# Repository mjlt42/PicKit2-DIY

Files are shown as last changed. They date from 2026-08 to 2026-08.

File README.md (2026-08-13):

PicKit 2 Bootloader Clone

# Description
This is clone of a PicKit 2, which is a bootloader for PIC MCU chips; requires a pre programmed chip to opperate. 

## Schematic:


## Bill Of Materials
| Reference | Qty | Value | Footprint | Datasheet |
| :--- | :---: | :--- | :--- | :--- |
| C1 | 1 | 47uF | JLCImport:ERS1KM470F12OT | — |
| C2, C3 | 2 | 22pF | JLCImport:CC1H220KA1EDCH4B1100 | — |
| C4 | 1 | 0.47uF | JLCImport:178MU0009 | — |
| C5 | 1 | 0.1uF | JLCImport:178MU0006 | — |
| D1 | 1 | BAT41 | JLCImport:BAT41 | [Datasheet](http://www.vishay.com/docs/85659/bat41.pdf) |
| D2 | 1 | 1N5817 | JLCImport:1N5817_C7544876 | [Datasheet](http://www.vishay.com/docs/88525/1n5817.pdf) |
| D3, D4 | 2 | LED | LED_THT:LED_D5.0mm | — |
| J1 | 1 | Conn_01x06_Socket | JLCImport:2_54-1_6PHeader-RA | — |
| J4 | 1 | USB_C_Receptacle_USB2.0_16P | JLCImport:KH-TYPE-C-16P | [Link](https://www.usb.org/sites/default/files/documents/usb_type-c.zip) |
| L1 | 1 | 680uH | JLCImport:YAL0410-681K | — |
| Q1, Q2, Q4 | 3 | 2N3904 | JLCImport:2N3904_C2874602 | [Datasheet](https://www.onsemi.com/pub/Collateral/2N3903-D.PDF) |
| Q3 | 1 | 2N3906 | JLCImport:2N3906_C2874603 | [Datasheet](https://www.onsemi.com/pub/Collateral/2N3906-D.PDF) |
| R1 | 1 | 1K | JLCImport:MF1_4W-1K_1_T52 | — |
| R2, R10, R15, R16 | 4 | 4.7K | JLCImport:MF1_4W-4_7K_1_T52 | — |
| R3 | 1 | 2.7K | JLCImport:MF1_4W-2_7K_1_T52 | — |
| R4 | 1 | 100K | JLCImport:MF1_4W-100K_1_T52 | — |
| R5, R6, R9 | 3 | 10K | JLCImport:MFR0W4F1002A50 | — |
| R7, R11 | 2 | 330 | JLCImport:MFR0W4F3300A50 | — |
| R8, R12, R13, R17 | 4 | 100 | JLCImport:MFR0W4F1000A50 | — |
| R14 | 1 | 22K | JLCImport:MF1_4W-22K_1_T52 | — |
| R18, R19 | 2 | 5.1K | JLCImport:MF1_4W-5_1K_1_T52 | — |
| SW1 | 1 | SW_Push | Button_Switch_THT:SW_PUSH_6mm | — |
| U1 | 1 | PIC18F2550-ISP | Package_DIP:DIP-28_W7.62mm | [Datasheet](http://ww1.microchip.com/downloads/en/devicedoc/39632c.pdf) |
| X1 | 1 | 20Mhz | JLCImport:X49ST2-20_000-F20JGDT | — |

## PCB Layout:
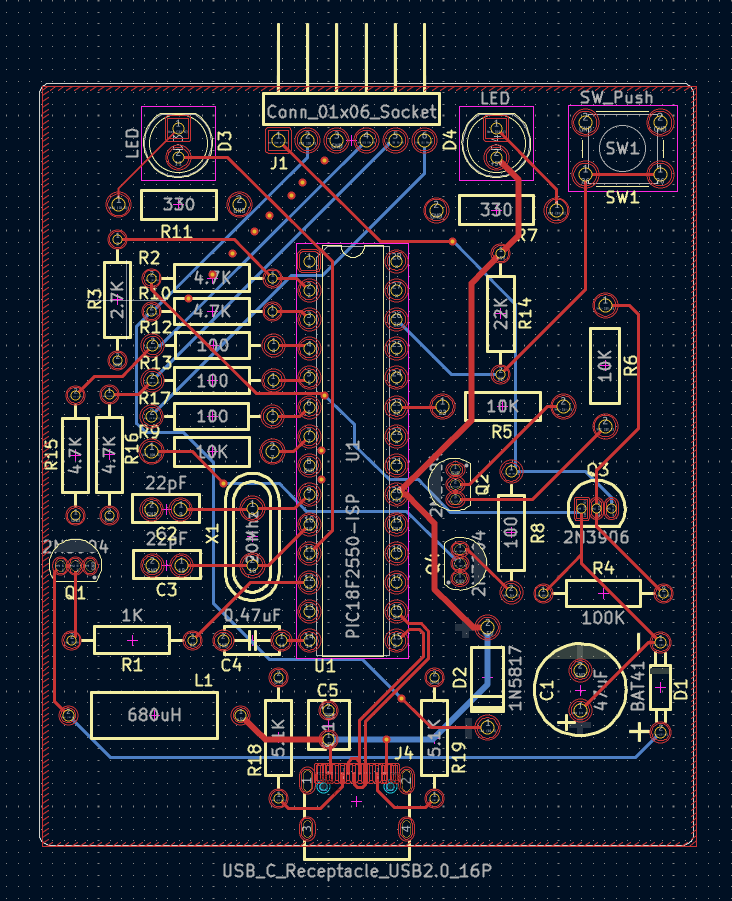
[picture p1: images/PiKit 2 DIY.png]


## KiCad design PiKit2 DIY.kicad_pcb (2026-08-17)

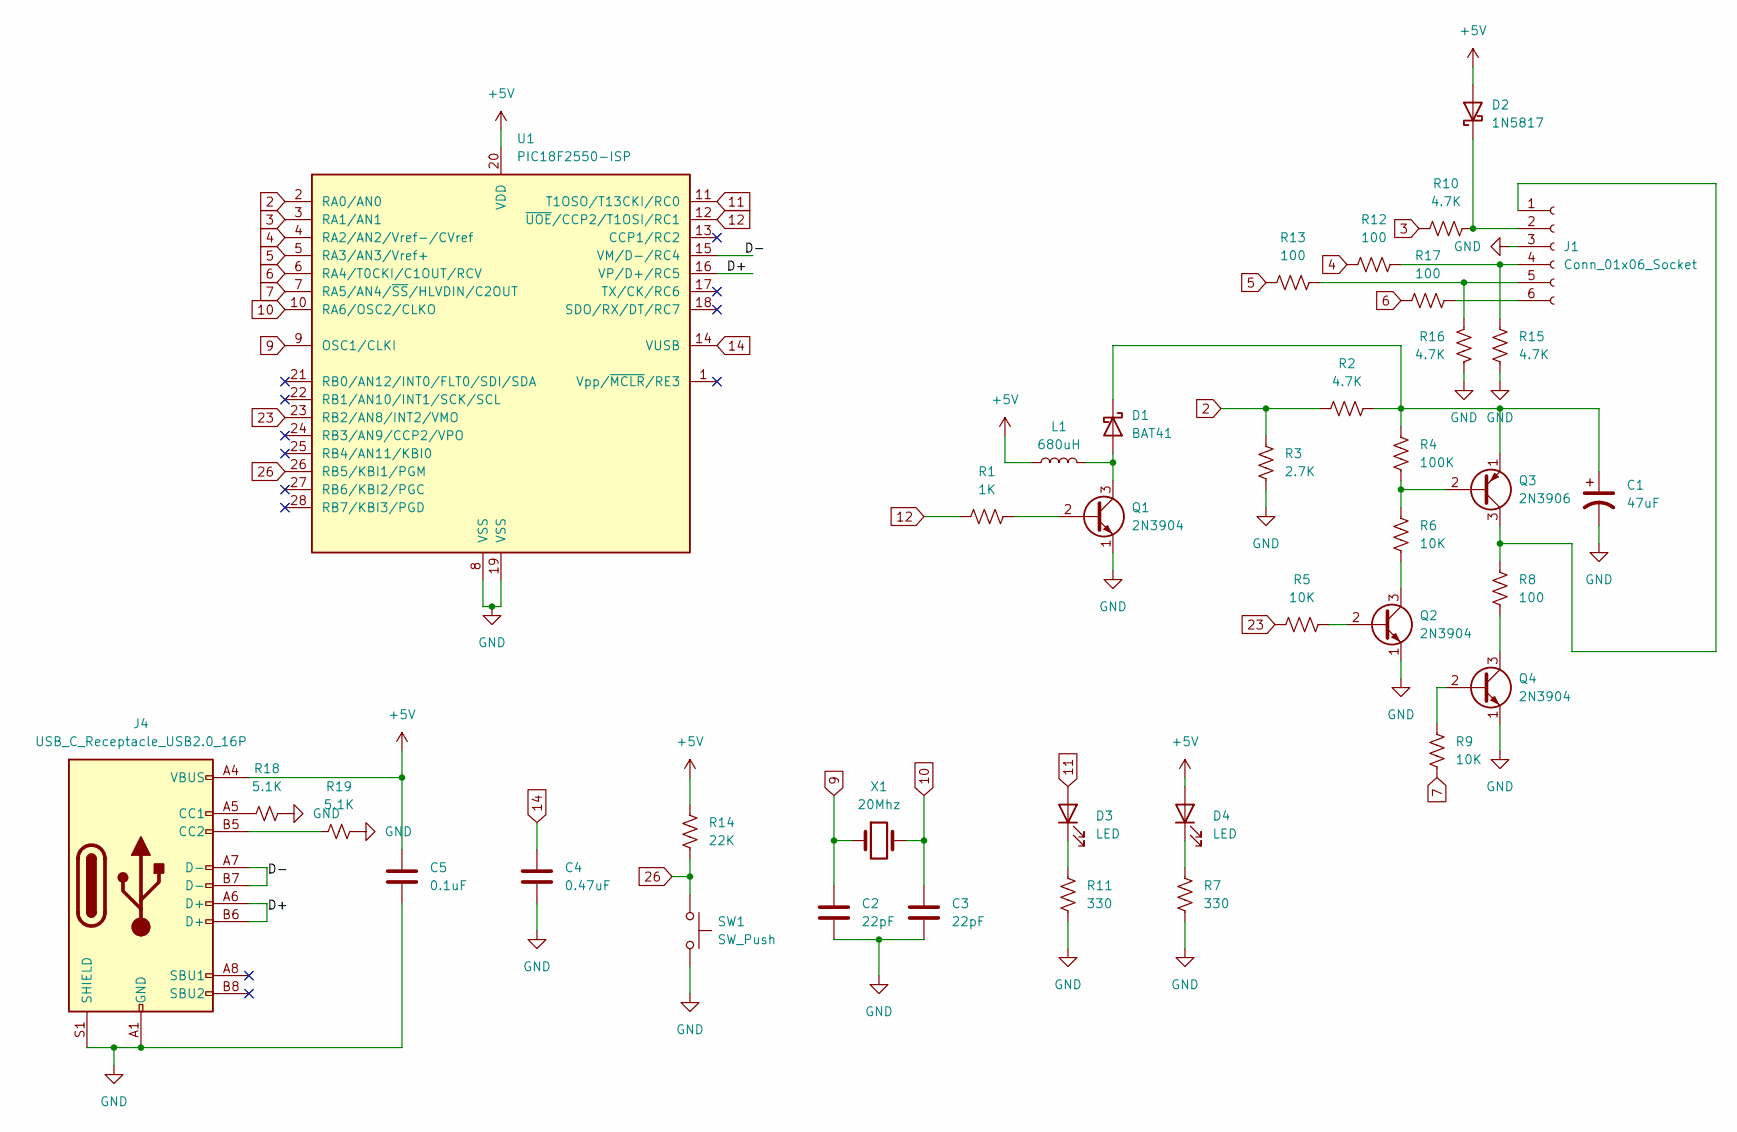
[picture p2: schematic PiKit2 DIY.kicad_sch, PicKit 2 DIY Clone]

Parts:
C1: 47uF; ERS1KM470F12OT
C2, C3: 22pF; CC1H220KA1EDCH4B1100
C4: 0.47uF; 178MU0009
C5: 0.1uF; 178MU0006
D1: BAT41
D2: 1N5817; 1N5817_C7544876
D3, D4: LED; LED_D5.0mm
J1: Conn_01x06_Socket; 2_54-1_6PHeader-RA
J4: USB_C_Receptacle_USB2.0_16P; KH-TYPE-C-16P
L1: 680uH; YAL0410-681K
Q1, Q2, Q4: 2N3904; 2N3904_C2874602
Q3: 2N3906; 2N3906_C2874603
R1: 1K; MF1_4W-1K_1_T52
R2, R10, R15, R16: 4.7K; MF1_4W-4_7K_1_T52
R3: 2.7K; MF1_4W-2_7K_1_T52
R4: 100K; MF1_4W-100K_1_T52
R5, R6, R9: 10K; MFR0W4F1002A50
R7, R11: 330; MFR0W4F3300A50
R8, R12, R13, R17: 100; MFR0W4F1000A50
R14: 22K; MF1_4W-22K_1_T52
R18, R19: 5.1K; MF1_4W-5_1K_1_T52
SW1: SW_Push; SW_PUSH_6mm
U1: PIC18F2550-ISP; DIP-28_W7.62mm
X1: 20Mhz; X49ST2-20_000-F20JGDT

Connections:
2: R2.1, R3.1, U1.2 (RA0/AN0)
3: R10.1, U1.3 (RA1/AN1)
4: R12.1, U1.4 (RA2/AN2/Vref-/CVref)
5: R13.1, U1.5 (RA3/AN3/Vref+)
6: R17.1, U1.6 (RA4/T0CKI/C1OUT/RCV)
7: R9.2, U1.7 (RA5/AN4/~SS/HLVDIN/C2OUT)
9: C2.1, U1.9 (OSC1/CLKI), X1.1
10: C3.1, U1.10 (RA6/OSC2/CLKO), X1.2
11: D3.2 (A), U1.11 (T1OSO/T13CKI/RC0)
12: R1.1, U1.12 (~UOE/CCP2/T1OSI/RC1)
14: C4.1, U1.14 (VUSB)
23: R5.1, U1.23 (RB2/AN8/INT2/VMO)
26: R14.2, SW1.1, U1.26 (RB5/KBI1/PGM)
+5V: C5.1, D2.2 (A), D4.2 (A), J4.A4 (VBUS), J4.A9 (VBUS), J4.B4 (VBUS), J4.B9 (VBUS), L1.1, R14.1, U1.20 (VDD)
/D+: J4.A6 (D+), J4.B6 (D+), U1.16 (VP/D+/RC5)
/D-: J4.A7 (D-), J4.B7 (D-), U1.15 (VM/D-/RC4)
GND: C1.2, C2.2, C3.2, C4.2, C5.2, J1.3, J4.A1 (GND), J4.A12 (GND), J4.B1 (GND), J4.B12 (GND), J4.S1 (SHIELD), Q1.1 (E), Q2.1 (E), Q4.1 (E), R3.2, R7.2, R11.2, R15.1, R16.2, R18.2, R19.2, SW1.2, U1.8 (VSS), U1.19 (VSS)
unnamed: D1.2 (A), L1.2, Q1.3 (C)
unnamed: C1.1, D1.1 (K), Q3.1 (E), R2.2, R4.1
unnamed: D2.1 (K), J1.2, R10.2
unnamed: D3.1 (K), R11.1
unnamed: D4.1 (K), R7.1
unnamed: J1.1, Q3.3 (C), R8.1
unnamed: J1.4, R12.2, R15.2
unnamed: J1.5, R13.2, R16.1
unnamed: J1.6, R17.2
unnamed: J4.A5 (CC1), R18.1
unnamed: J4.B5 (CC2), R19.1
unnamed: Q1.2 (B), R1.2
unnamed: Q2.2 (B), R5.2
unnamed: Q2.3 (C), R6.2
unnamed: Q3.2 (B), R4.2, R6.1
unnamed: Q4.2 (B), R9.1
unnamed: Q4.3 (C), R8.2

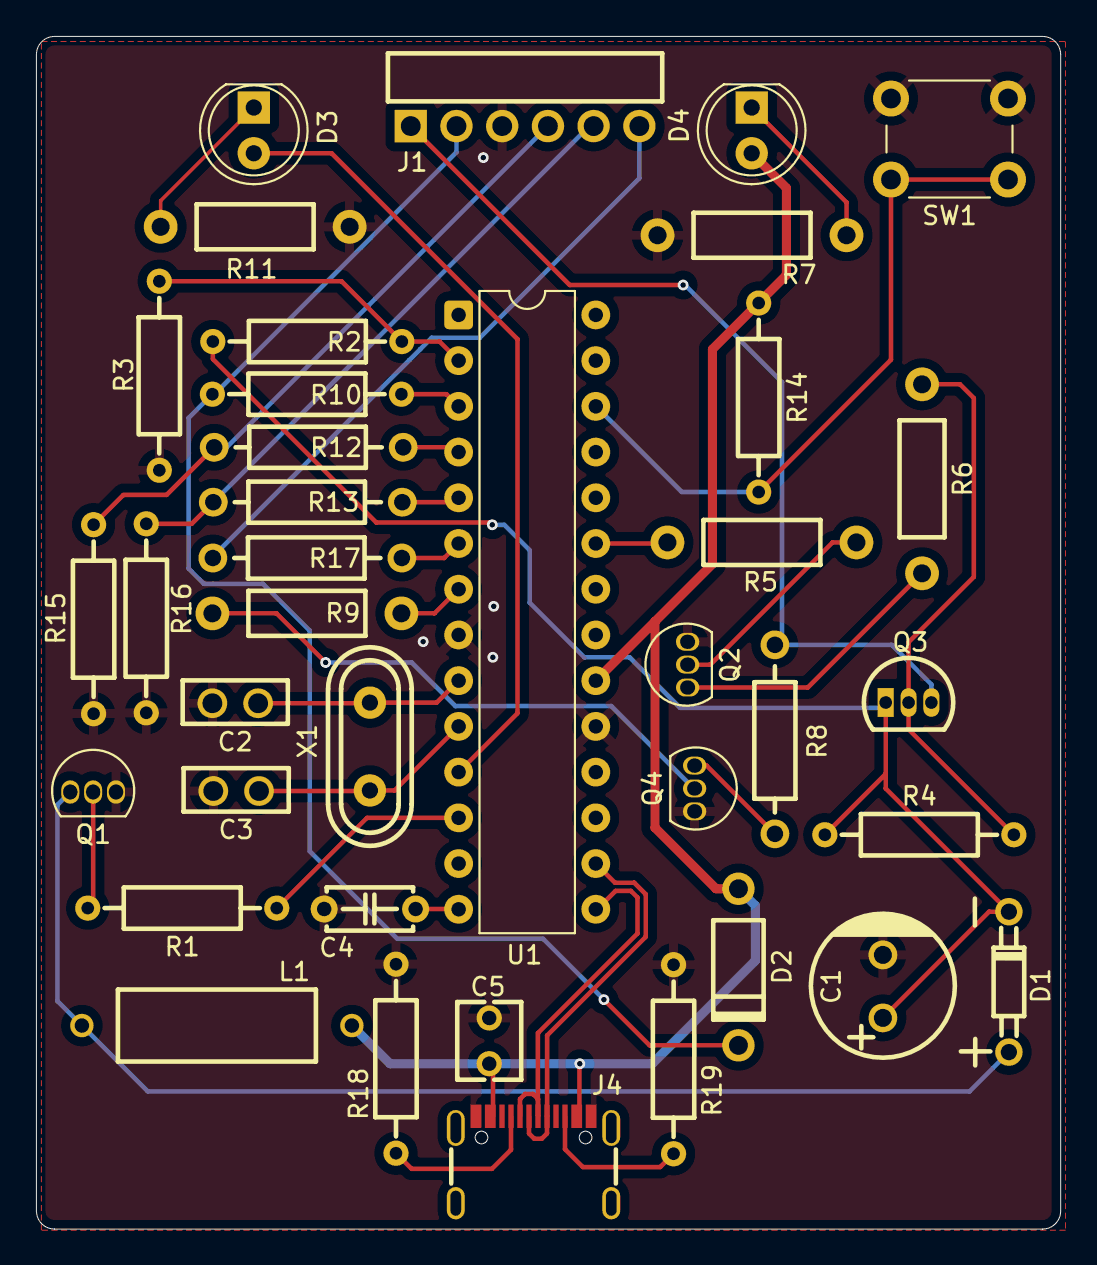
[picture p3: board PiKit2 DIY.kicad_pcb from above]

Board: 2 copper layers, 56.9 x 66.3 mm, 38 parts (0 on the bottom side), 34 nets.

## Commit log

2026-07-27 Update .gitignore for KiCAD and Python files
    Add KiCAD library table files (fp-lib-table, sym-lib-table) and Python cache directory (__pycache__/) to gitignore. These are build artifacts and generated files that shouldn't be committed to the re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
2026-07-27 Initialize README with project details
    Added project title and schematic image to README.
2026-07-27 Move schematic elements and enable ngspice
    Repositioned multiple circuit elements on the schematic and added ngspice configuration to project settings. Auto-backup created by KiCad during the changes.
    [PiKit2 DIY.kicad_sch]
2026-07-30 Imported JLCPCB Footprints and 3D Models
    [PiKit2 DIY.kicad_sch]
2026-08-02 Added Resistor Footprints and models
    [PiKit2 DIY.kicad_sch]
2026-08-02 Import full PCB, fix schematic label, add backups
    Replace PiKit2 DIY.kicad_pcb with the full KiCad 9 PCB data (generated by pcbnew). Update PiKit2 DIY.kicad_sch global_label from "9" to "7". Add four backup zip archives under PiKit2 DIY-backups for recent snapshots.
    [PiKit2 DIY.kicad_pcb, PiKit2 DIY.kicad_sch]
2026-08-04 Updated 100 ohm R model and footprint; Finished component placement; began routing traces
    [PiKit2 DIY.kicad_pcb, PiKit2 DIY.kicad_sch]
2026-08-07 KiCad: add stackup, fix nets and footprints
    Add PCB stackup and layer definitions; remap many net indices and correct USB D+/D- nets and Type-C pin mappings. Adjust footprint positions, pad orientations and UUIDs, update routing (including a tuned pattern for a route), and fix silkscreen geometry. Update schematic: add D+/D- labels/wires and remove redundant global labels. Add/remove several backup zip files. These edits correct net assignments, improve component placement/orientation and refine USB routing.
    [PiKit2 DIY.kicad_pcb, PiKit2 DIY.kicad_sch]
2026-08-08 Finished traces; added design rule check; added copper pours
    [PiKit2 DIY.kicad_pcb]
2026-08-08 Enhance README with description and PCB layout
    Added a description section and PCB layout image to README.
2026-08-13 Ignore .zip backups and update KiCad project
    Add '*.zip' to .gitignore and remove a committed backup archive. Clean up the KiCad project file by removing several hole_clearance DRC exclusions and set the project 'plot' path to 'Pikit2 DIY Produ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
2026-08-13 Update to images
    [PiKit2 DIY.kicad_pcb, PiKit2 DIY.kicad_sch]
2026-08-13 Add interactive KiCAD BOM HTML (ibom.html)
    Add bom/ibom.html — a complete Interactive BOM page for KiCAD. Includes Split.js, LZString, PointerEvents polyfill and code to render front/back PCB canvases, BOM table, filtering, sorting, checkbox state persistence, settings import/export, image and CSV export, net coloring, zoom/pan, highlights and keyboard shortcuts. Stores user preferences in web storage and exposes event hooks for integrations.
2026-08-13 Fixed some DFM violations
    [PiKit2 DIY.kicad_pcb]
2026-08-17 Update PCB layout, DRC rules; remove backup zips
    Remove old backup zip archives and apply multiple PCB updates. PiKit2 DIY.kicad_pcb: adjust several component positions (R18, R19, U1...), refresh many element UUIDs, remove/clean up F.SilkS silkscreen lines, and add/modify copper segments/vias and routing to correct nets. Large vertex/path data updated (smoothing/coordinate fixes). PiKit2 DIY.kicad_pro: update DRC exclusions (add hole_clearance entries and several starved_thermal entries for new coordinates) and add a 0.3 entry to the track/pour widths. These changes tidy layout and DRC settings to match the revised routing.
    [PiKit2 DIY.kicad_pcb]
2026-08-17 updated BOM file
2026-08-17 Add json/ipc to .gitignore; update KiCad files
    Add '*.json' and '*.ipc' to .gitignore and remove two backup .zip files. Apply edits to PiKit2 DIY.kicad_pcb (minor coordinate/shape adjustments) and change solder_mask_to_copper_clearance from 0.0 t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
    [PiKit2 DIY.kicad_pcb]
